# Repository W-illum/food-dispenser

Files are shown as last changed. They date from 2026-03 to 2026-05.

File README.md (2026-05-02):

# Automatic Food Dispenser

Firmware for an Arduino Nano ESP32-based automatic cat food dispenser. Controls a stepper motor to dispense food on a configurable schedule. Can be controlled from a phone using the companion app:
[https://github.com/W-illum/food-dispenser-app/](https://github.com/W-illum/food-dispenser-app/)

---

## Overview

The feeder runs on an Arduino Nano ESP32 and exposes a GATT BLE service. All feeding logic lives on the device, the app is purely a remote control. It can also be operated standalone using the rotary encoder and OLED display on the device itself. The hardware is built on a custom 2-layer PCB designed in KiCad.

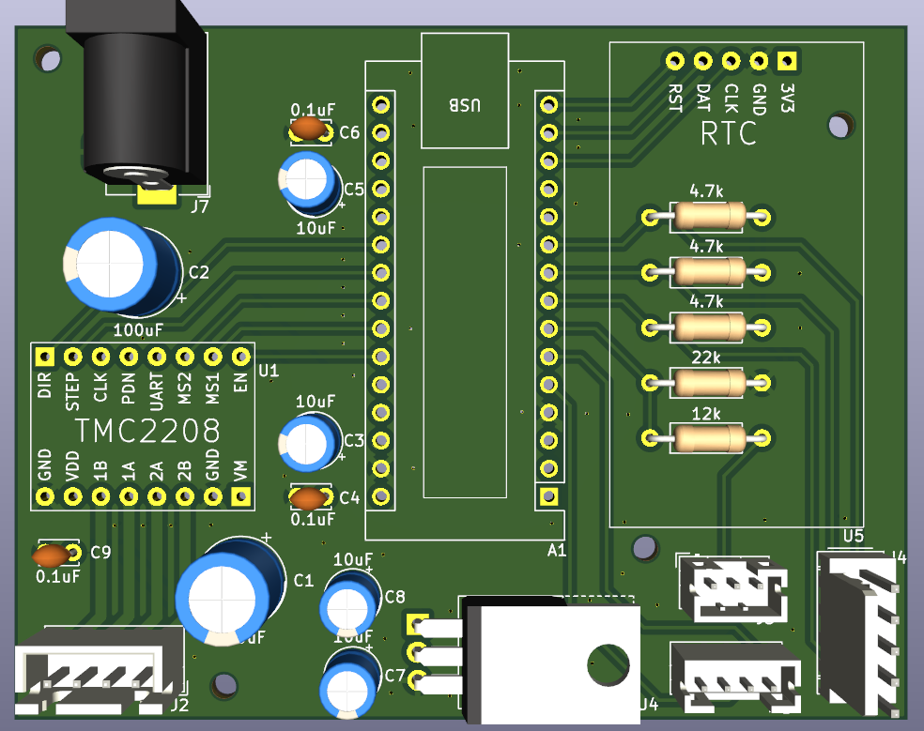
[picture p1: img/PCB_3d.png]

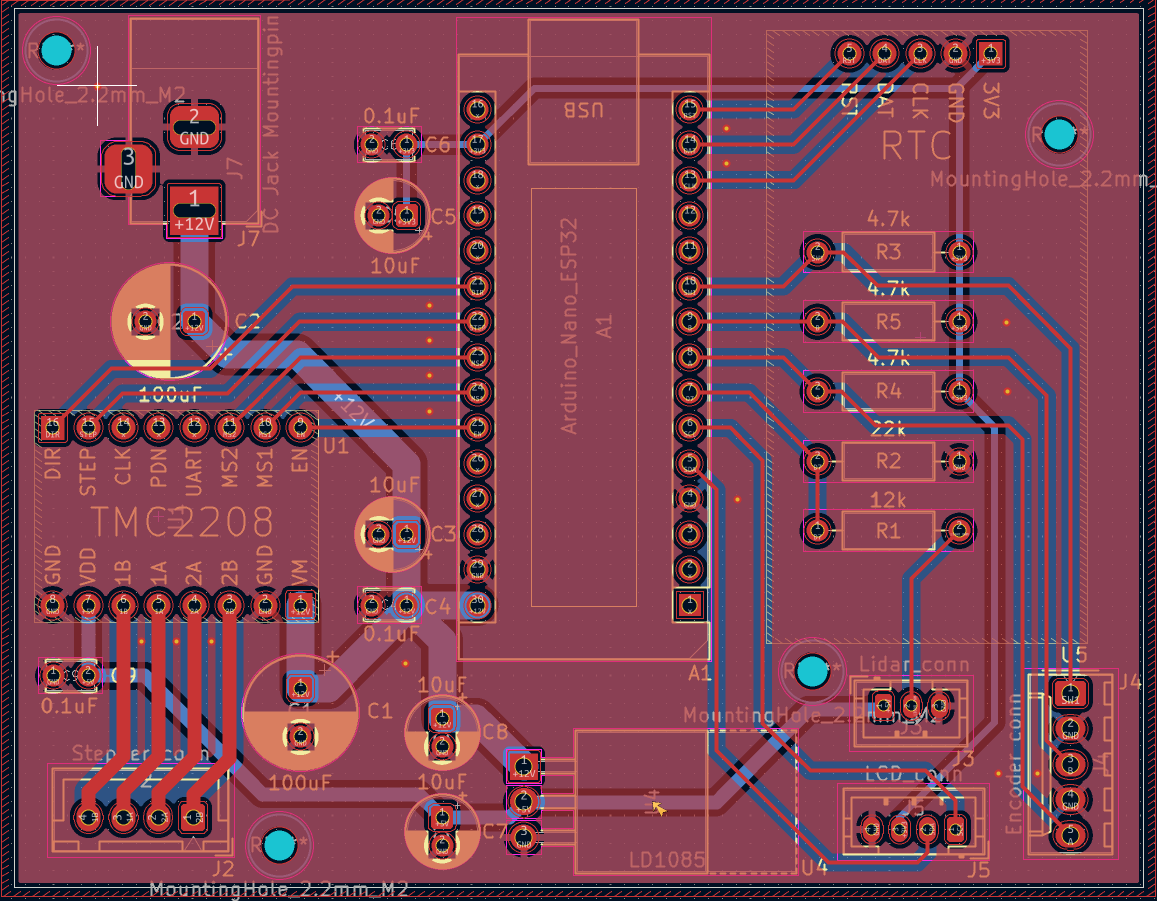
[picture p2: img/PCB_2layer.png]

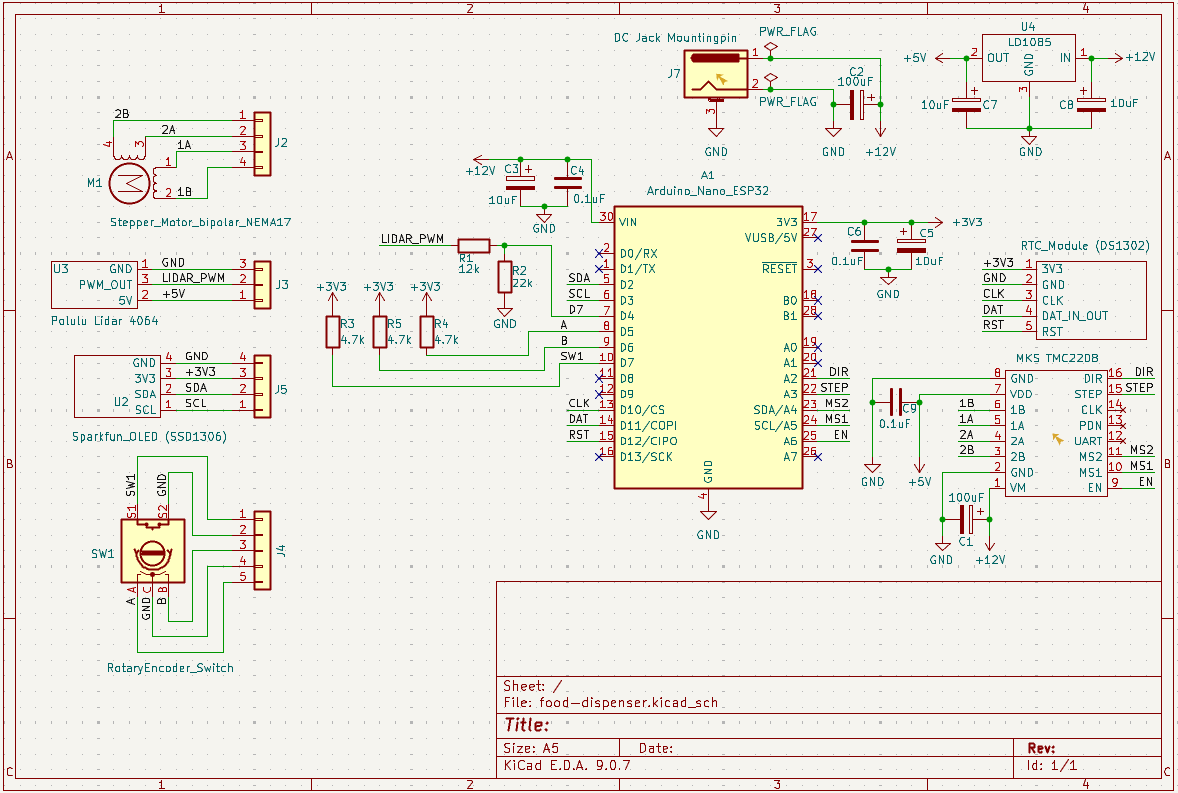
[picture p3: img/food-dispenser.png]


---

## Features

- **Scheduled feeding** - stores up to 4 feeding times in EEPROM, executed automatically via RTC
- **OLED display & rotary encoder** - fully standalone control without a phone
- **BLE control** - exposes a GATT service for remote control via the companion app
- **Manual feed** - dispense food on demand over BLE
- **Food level sensing** - LiDAR-based food level monitoring
- **Stepper motor control** - TMC driver with timer-ISR driven stepping

---

## Hardware

- Arduino Nano ESP32
- TMC stepper driver
- Nema stepper motor
- DS1302 RTC
- SparkFun Qwiic OLED display
- Rotary encoder
- LiDAR food level sensor

---

## Tech Stack

- [PlatformIO](https://platformio.org) / Arduino framework
- [NimBLE-Arduino](https://github.com/h2zero/NimBLE-Arduino) - BLE stack
- C++

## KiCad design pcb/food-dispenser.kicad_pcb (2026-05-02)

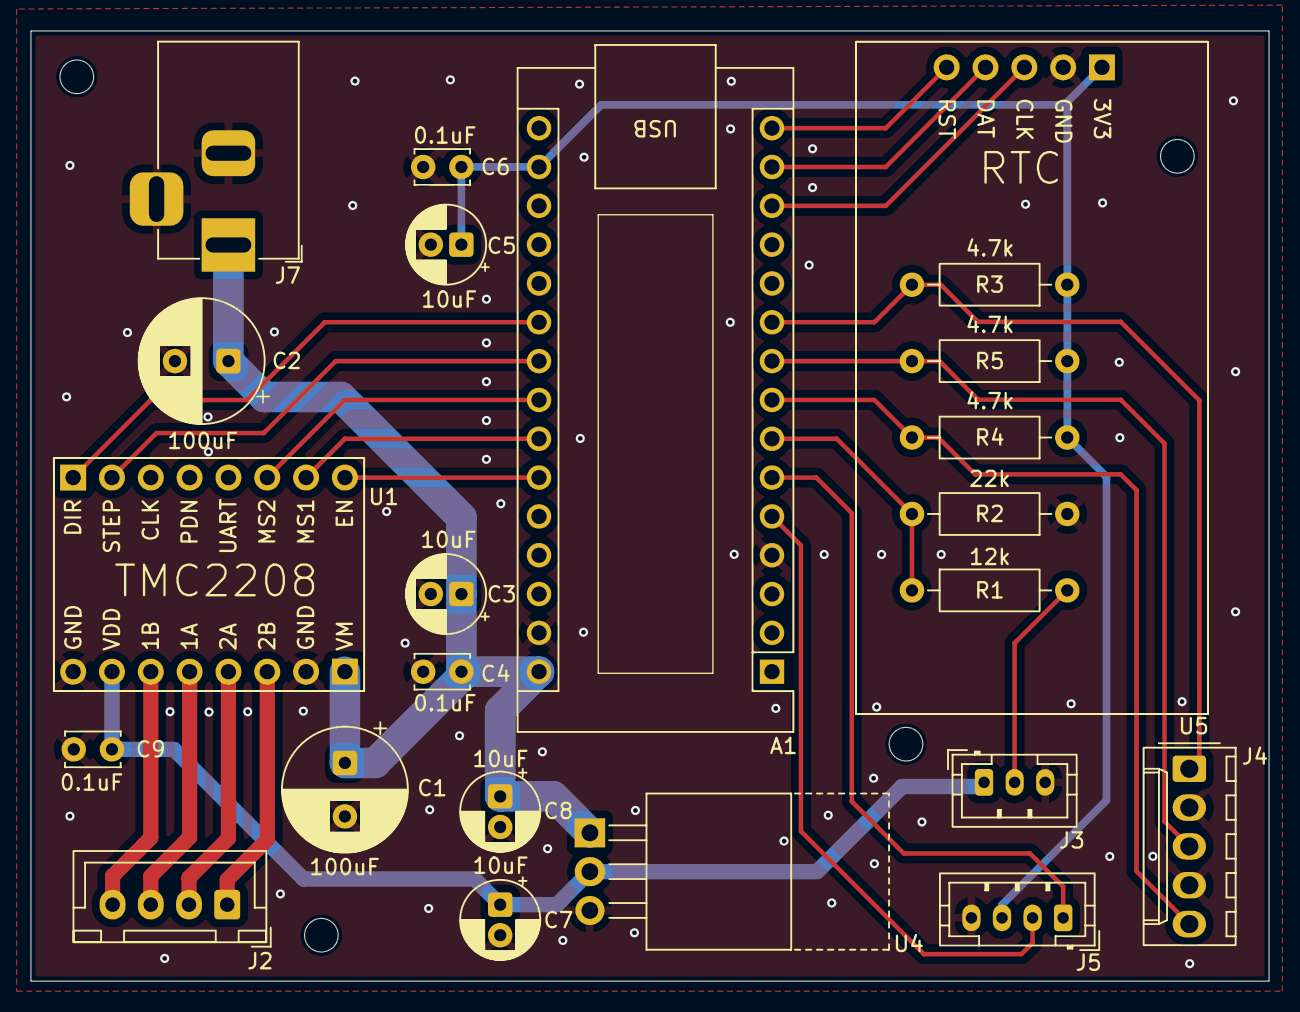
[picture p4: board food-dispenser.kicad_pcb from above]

Board: 2 copper layers, 81.0 x 62.2 mm, 23 parts (0 on the bottom side), 23 nets.

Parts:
A1: Arduino_Nano_ESP32; Arduino_Nano
C1, C2: 100uF; CP_Radial_D8.0mm_P3.50mm
C3, C5, C7, C8: 10uF; CP_Radial_D5.0mm_P2.00mm
C4, C6, C9: 0.1uF; C_Disc_D3.4mm_W2.1mm_P2.50mm
J2: Stepper_conn; JST_XH_B4B-XH-A_1x04_P2.50mm_Vertical
J3: Lidar_conn; JST_PH_B3B-PH-K_1x03_P2.00mm_Vertical
J4: Encoder_conn; Molex_KK-254_AE-6410-05A_1x05_P2.54mm_Vertical
J5: LCD_conn; JST_PH_B4B-PH-K_1x04_P2.00mm_Vertical
J7: DC Jack Mountingpin; BarrelJack_Horizontal
R1: 12k; R_Axial_DIN0207_L6.3mm_D2.5mm_P10.16mm_Horizontal
R2: 22k; R_Axial_DIN0207_L6.3mm_D2.5mm_P10.16mm_Horizontal
R3, R4, R5: 4.7k; R_Axial_DIN0207_L6.3mm_D2.5mm_P10.16mm_Horizontal
U1: MKS TMC2208; MKS TMC_2208 Module
U4: LD1085; TO-220-3_Horizontal_TabUp
U5: RTC_Module (DS1302); RTC Module(DS1302)

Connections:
+3V3: A1.17 (3V3), C5.1, C6.1, J5.3, R3.1, R4.1, R5.1, U5.1 (3V3)
+5V: C7.1, C9.2, J3.1, U1.7 (VDD), U4.2 (OUT)
+12V: A1.30 (VIN), C1.1, C2.1, C3.1, C4.1, C8.1, J7.1, U1.1 (VM), U4.1 (IN)
/1A: J2.3, U1.5 (1A)
/1B: J2.4, U1.6 (1B)
/2A: J2.2, U1.4 (2A)
/2B: J2.1, U1.3 (2B)
/A: A1.8 (D5), J4.5, R4.2
/B: A1.9 (D6), J4.3, R5.2
/CLK: A1.13 (D10/CS), U5.3 (CLK)
/D7: A1.7 (D4), R1.1, R2.2
/DAT: A1.14 (D11/COPI), U5.4 (DAT_IN_OUT)
/DIR: A1.21 (A2), U1.16 (DIR)
/EN: A1.25 (A6), U1.9 (EN)
/LIDAR_PWM: J3.2, R1.2
/MS1: A1.24 (SCL/A5), U1.10 (MS1)
/MS2: A1.23 (SDA/A4), U1.11 (MS2)
/RST: A1.15 (D12/CIPO), U5.5 (RST)
/SCL: A1.6 (D3), J5.1
/SDA: A1.5 (D2), J5.2
/STEP: A1.22 (A3), U1.15 (STEP)
/SW1: A1.10 (D7), J4.1, R3.2
GND: A1.4 (GND), A1.29 (GND), C1.2, C2.2, C3.2, C4.2, C5.2, C6.2, C7.2, C8.2, C9.1, J3.3, J4.2, J4.4, J5.4, J7.2, J7.3 (MountPin), R2.1, U1.2 (GND), U1.8 (GND), U4.3 (GND), U5.2 (GND)

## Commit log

2026-02-02 Started on Rotary Encoder, needs better debounce
2026-02-02 minimized debounce on rotation and button (not 100% perfect)
2026-02-04 simple no timer/interrupt test for motor
2026-02-05 changed to esp pins instead of arduino
2026-02-05 timer interrupts on motor
2026-02-05 working stepper + encoder
2026-02-07 tested lcd, motor and lidar (lidar needs 5V)
2026-02-08 only enable motor driver when we need it
2026-02-12 Added Menu class, using LCD functions, reacting on encoder click and rotation
2026-03-05 added rtc and tested lidar code
2026-03-06 added schematic and pcb picture
2026-03-26 Added feeder logic and lidar (Version 1), TODO: test motor rotation and food amount values
2026-05-02 pcb files
    [food-dispenser.kicad_pcb, food-dispenser.kicad_sch]
